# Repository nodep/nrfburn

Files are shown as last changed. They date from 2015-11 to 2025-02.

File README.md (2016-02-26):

# nrfburn
This is a hardware and software package for flashing Nordic Semiconductors nRF24LE1 and nRF24LU1+ microcontrollers. It consists of three parts: the flasher device with a USB connection, the firmware running on the flasher, and a host program which sends command to the flasher over the USB connection.

### The flasher

The flasher is based around an Atmel AVR ATmega88pa microcontroller running at 12MHz and 3.3V. The PCB is a mixture of through-hole and SMD components chosen as a compromise between size, ease of hand-soldering and mechanical robustness.

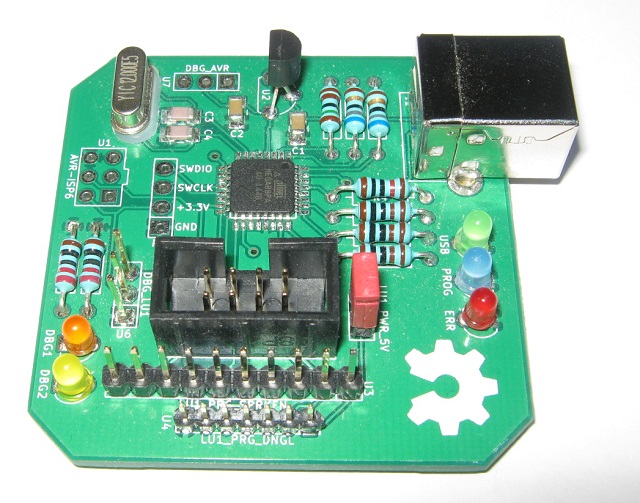
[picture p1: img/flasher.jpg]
the flasher v1.1


It has connectors with pin configurations which allow two popular nRF24LU1+ breakouts and dongles to be directly plugged into the flasher. One is the SparkFun Tranciever Breakout - nRF24LU1+, and the other is the popular nRF USB dongle from ebay.

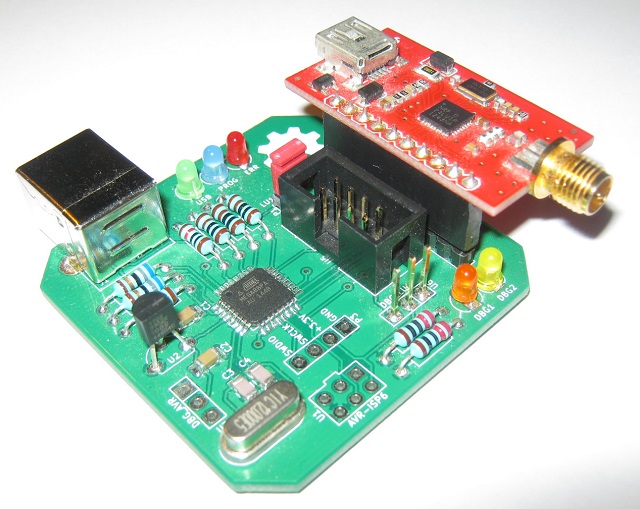
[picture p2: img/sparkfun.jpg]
the flasher and SparkFun

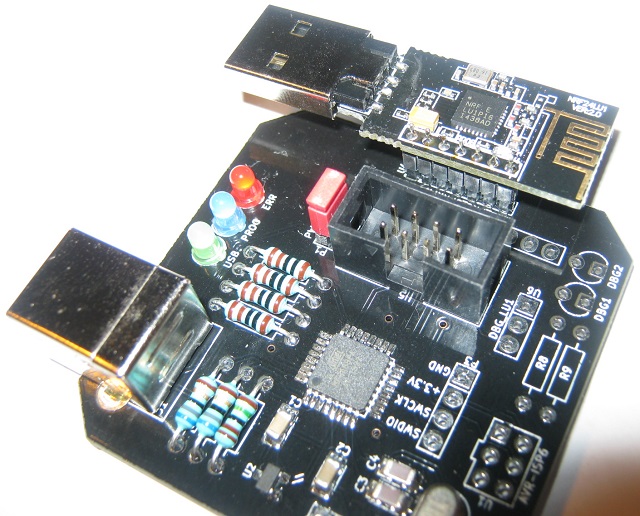
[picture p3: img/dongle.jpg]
the flasher and the ebay dongle


It also has an 8 pin flat cable connector through which it can flash nRF24LE1 devices as an in-system programmer.

The DBG_LU1 output can be used as a UART debug output from the nRF24LU1+ dongle. There are also two LEDs (DBG1 and DBG2) which can be driven from the SparkFun breakout. This is also useful for debugging.

### The firmware

The flasher firmware communicates with the host PC though [obdev's V-USB](https://www.obdev.at/products/vusb/index.html). It accepts commands from the PC, executes them and sends responses.

### The host PC

The program running on the host PC is a cross-platform (Windows and Linux) command line tool. It does not need special OS drivers because all communication is done through the USB HID class. It's been tested on Windows 7, 8 and 10 and on Linux running on Hardkernel's Odroid X2 board.

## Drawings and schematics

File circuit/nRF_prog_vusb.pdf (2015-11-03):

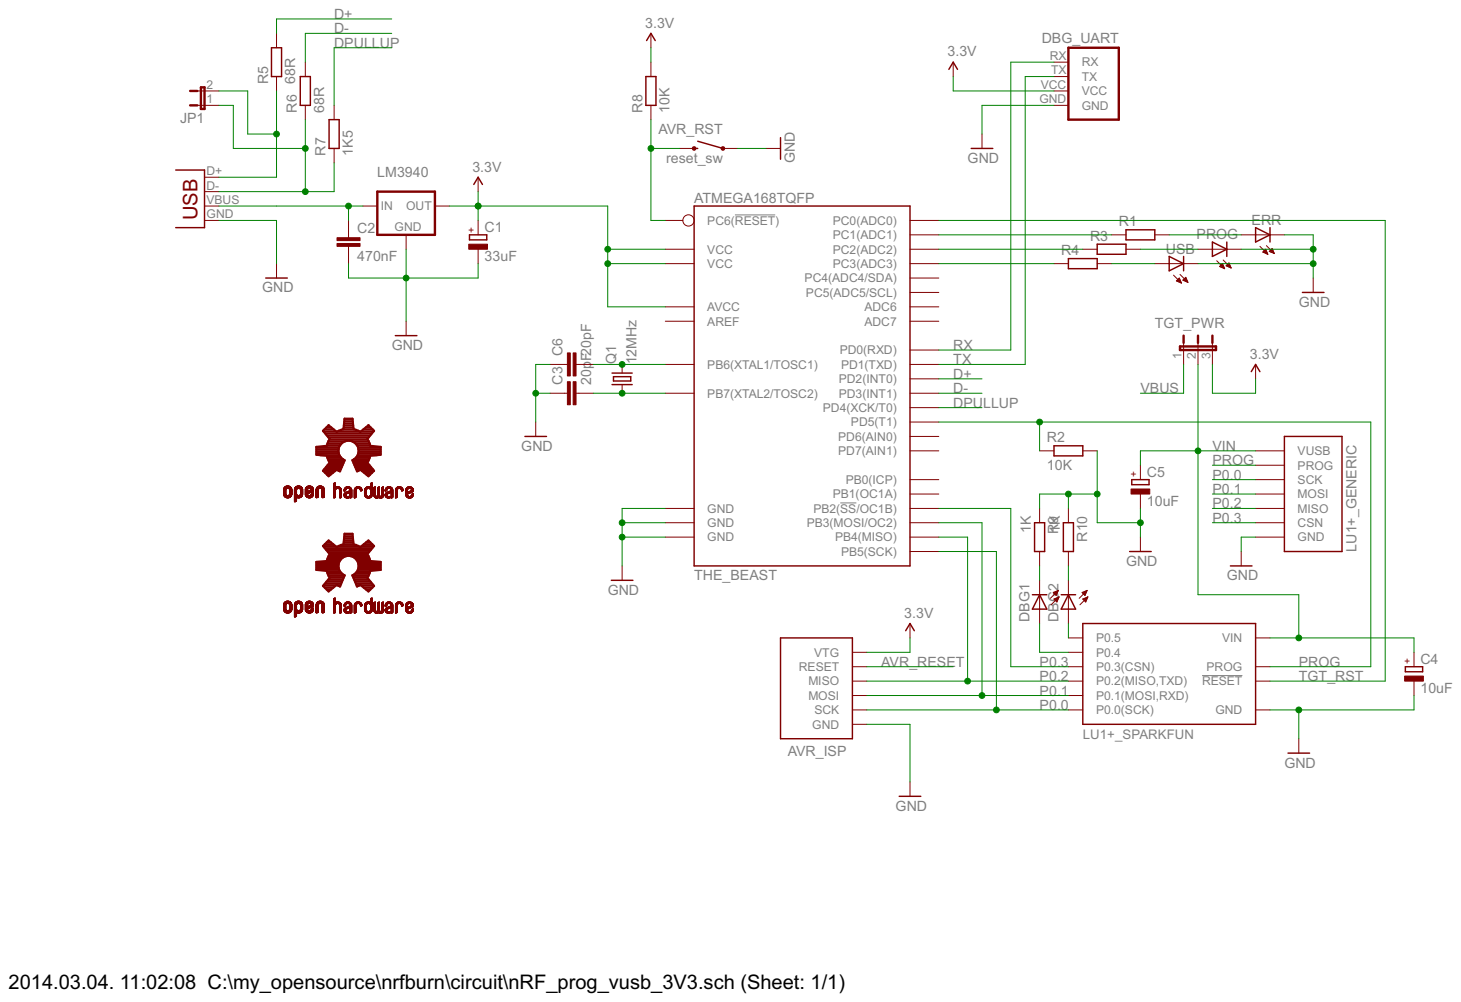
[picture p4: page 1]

2014.03.04. 11:02:08 C:\my_opensource\nrfburn\circuit\nRF_prog_vusb_3V3.sch (Sheet: 1/1)

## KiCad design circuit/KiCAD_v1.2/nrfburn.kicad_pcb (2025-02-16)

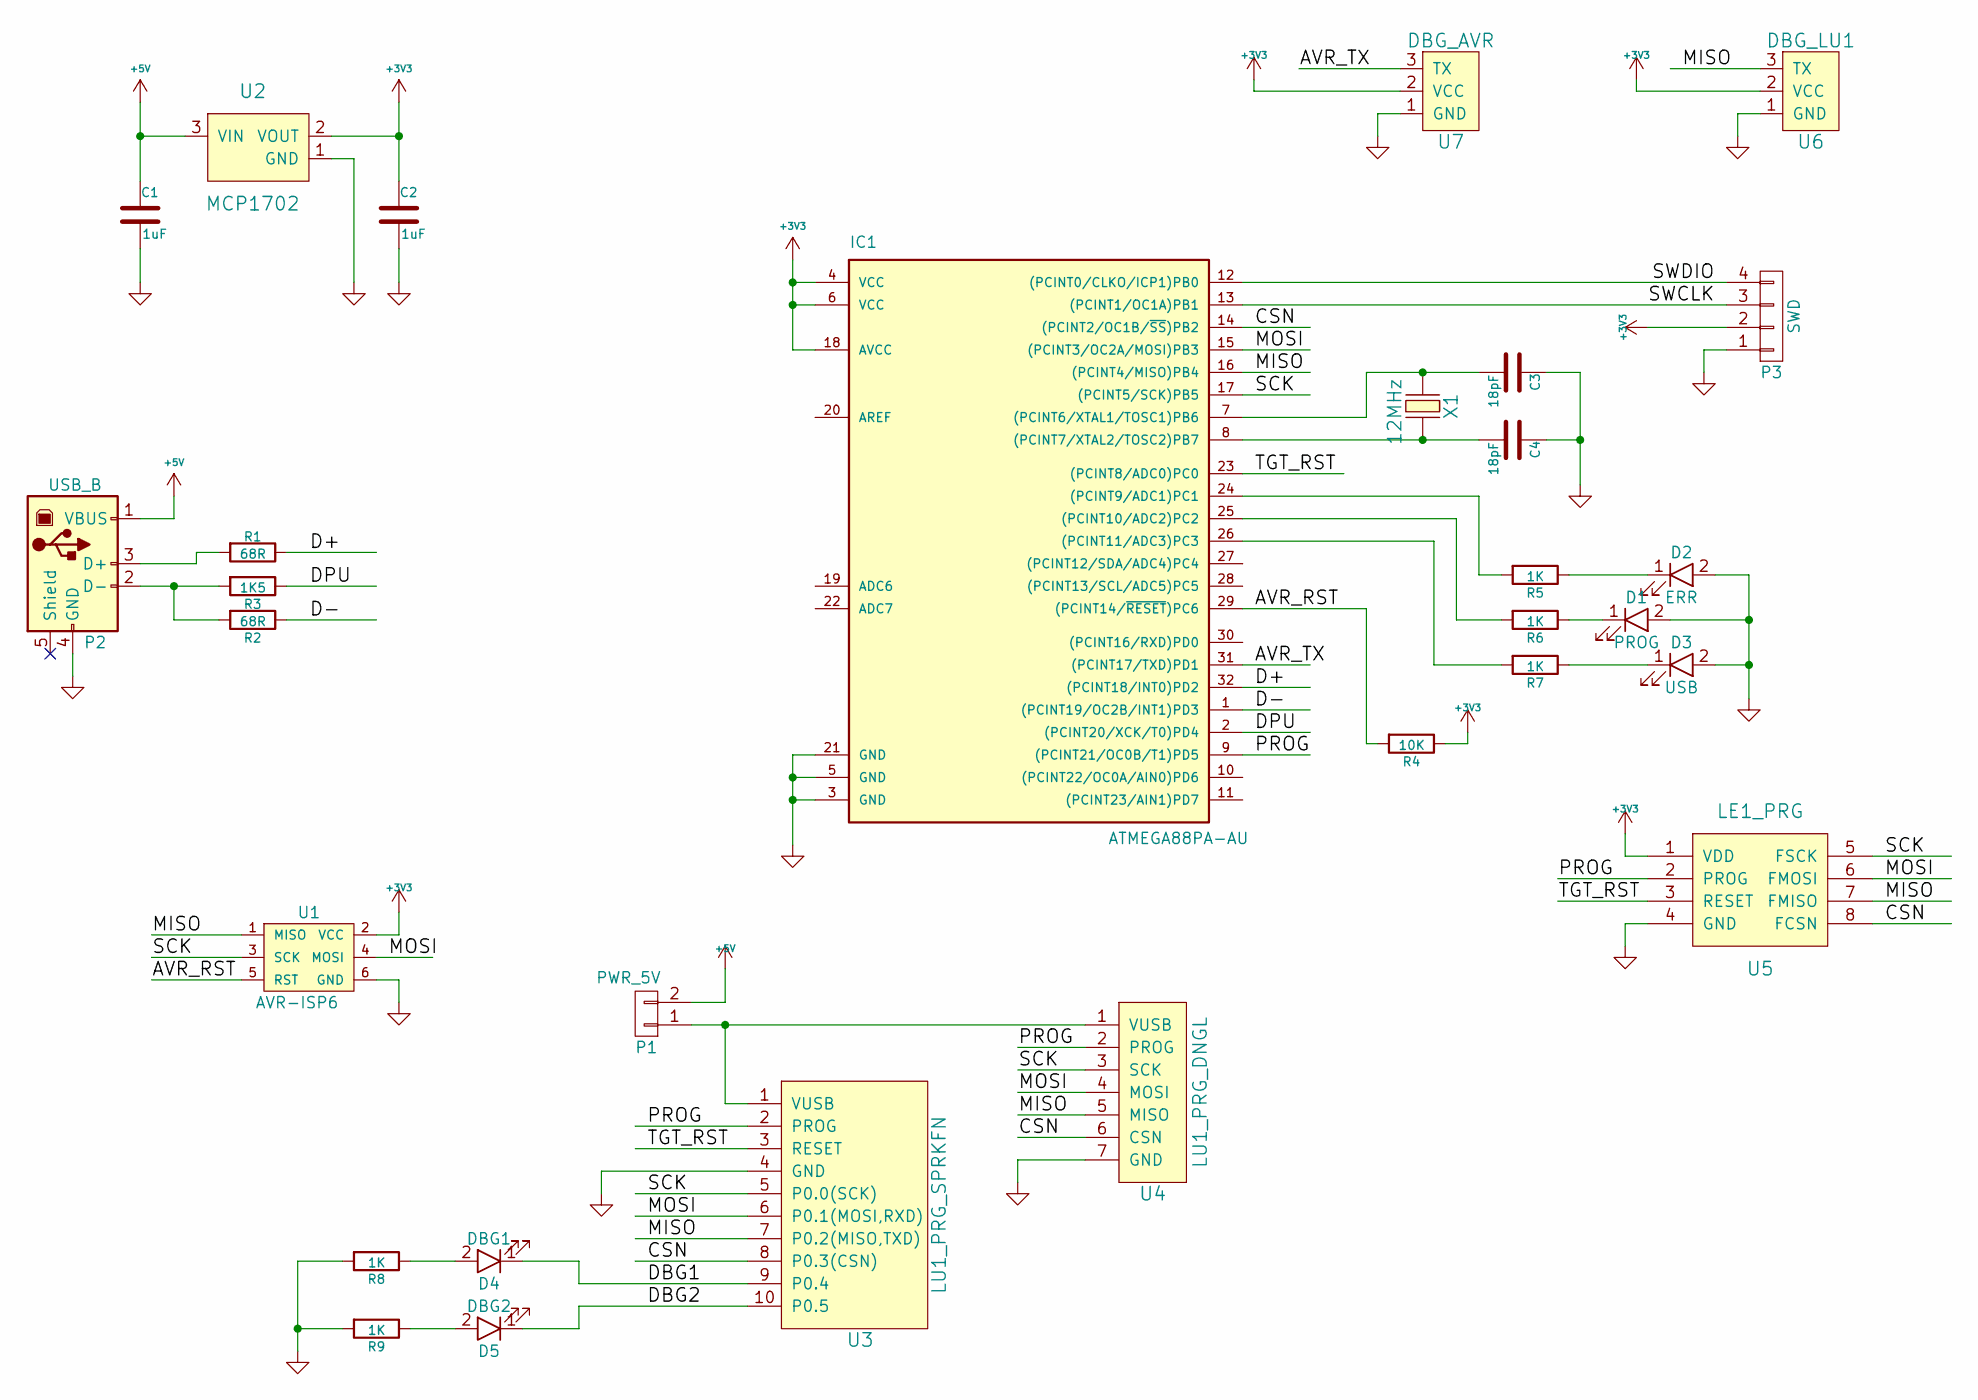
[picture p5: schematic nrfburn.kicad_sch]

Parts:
C1, C2: 1uF; c_1206
C3, C4: 18pF; c_1206
D1: PROG; LED-3MM
D2: ERR; LED-3MM
D3: USB; LED-3MM
D4: DBG1; LED-3MM
D5: DBG2; LED-3MM
IC1: ATMEGA88PA-AU; TQFP32
P1: PWR_5V; Pin_Header_Straight_1x02
P2: USB_B; USB_B_loc
P3: SWD; Pin_Header_Straight_1x04
R1, R2: 68R; Resistor_Horizontal_RM10mm
R3: 1K5; Resistor_Horizontal_RM10mm
R4: 10K; Resistor_Horizontal_RM10mm
R5, R6, R7, R8, R9: 1K; Resistor_Horizontal_RM10mm
U1: AVR-ISP6; AVR_ISP6
U2: MCP1702; SOT23
U3: LU1_PRG_SPRKFN; Pin_Header_Straight_1x10
U4: LU1_PRG_DNGL; LU1_PRG_DONGLE
U5: LE1_PRG; NRF_ICSP_RibbonCable
U6: DBG_LU1; Pin_Header_Straight_1x03
U7: DBG_AVR; Pin_Header_Straight_1x03
X1: 12MHz; Crystal_HC49-U_Vertical

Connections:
+3V3: C2.1, IC1.4 (VCC), IC1.6 (VCC), IC1.18 (AVCC), P3.2, R4.1, U1.2 (VCC), U2.2 (VOUT), U5.1 (VDD), U6.2 (VCC), U7.2 (VCC)
+5V: C1.1, P1.2, P2.1 (VBUS), U2.3 (VIN)
/AVR_RST: IC1.29 ((PCINT14/~RESET)PC6), R4.2, U1.5 (RST)
/AVR_TX: IC1.31 ((PCINT17/TXD)PD1), U7.3 (TX)
/CSN: IC1.14 ((PCINT2/OC1B/~SS)PB2), U3.8 (P0.3(CSN)), U4.6 (CSN), U5.8 (FCSN)
/D+: IC1.32 ((PCINT18/INT0)PD2), R1.1
/D-: IC1.1 ((PCINT19/OC2B/INT1)PD3), R2.1
/DBG1: D4.1 (K), U3.9 (P0.4)
/DBG2: D5.1 (K), U3.10 (P0.5)
/DPU: IC1.2 ((PCINT20/XCK/T0)PD4), R3.1
/MISO: IC1.16 ((PCINT4/MISO)PB4), U1.1 (MISO), U3.7 (P0.2(MISO,TXD)), U4.5 (MISO), U5.7 (FMISO), U6.3 (TX)
/MOSI: IC1.15 ((PCINT3/OC2A/MOSI)PB3), U1.4 (MOSI), U3.6 (P0.1(MOSI,RXD)), U4.4 (MOSI), U5.6 (FMOSI)
/PROG: IC1.9 ((PCINT21/OC0B/T1)PD5), U3.2 (PROG), U4.2 (PROG), U5.2 (PROG)
/SCK: IC1.17 ((PCINT5/SCK)PB5), U1.3 (SCK), U3.5 (P0.0(SCK)), U4.3 (SCK), U5.5 (FSCK)
/SWCLK: IC1.13 ((PCINT1/OC1A)PB1), P3.3
/SWDIO: IC1.12 ((PCINT0/CLKO/ICP1)PB0), P3.4
/TGT_RST: IC1.23 ((PCINT8/ADC0)PC0), U3.3 (RESET), U5.3 (RESET)
GND: C1.2, C2.2, C3.1, C4.1, D1.2 (A), D2.2 (A), D3.2 (A), IC1.3 (GND), IC1.5 (GND), IC1.21 (GND), P2.4 (GND), P3.1, R8.2, R9.2, U1.6 (GND), U2.1 (GND), U3.4 (GND), U4.7 (GND), U5.4 (GND), U6.1 (GND), U7.1 (GND)
unnamed: D1.1 (K), R6.1
unnamed: D2.1 (K), R5.1
unnamed: D3.1 (K), R7.1
unnamed: D4.2 (A), R8.1
unnamed: D5.2 (A), R9.1
unnamed: C3.2, IC1.7 ((PCINT6/XTAL1/TOSC1)PB6), X1.1
unnamed: C4.2, IC1.8 ((PCINT7/XTAL2/TOSC2)PB7), X1.2
unnamed: IC1.24 ((PCINT9/ADC1)PC1), R5.2
unnamed: IC1.25 ((PCINT10/ADC2)PC2), R6.2
unnamed: IC1.26 ((PCINT11/ADC3)PC3), R7.2
unnamed: P1.1, U3.1 (VUSB), U4.1 (VUSB)
unnamed: P2.3 (D+), R1.2
unnamed: P2.2 (D-), R2.2, R3.2

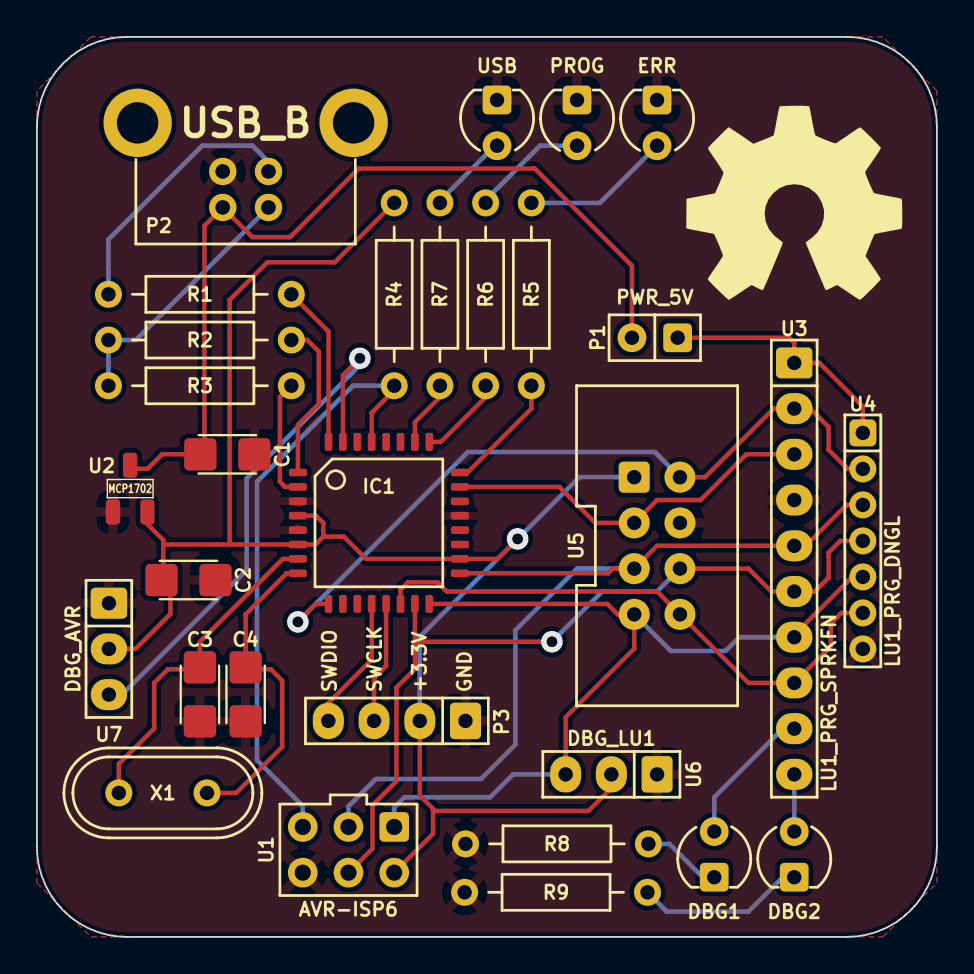
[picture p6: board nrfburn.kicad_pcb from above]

Board: 2 copper layers, 50.0 x 50.0 mm, 30 parts (0 on the bottom side), 31 nets.

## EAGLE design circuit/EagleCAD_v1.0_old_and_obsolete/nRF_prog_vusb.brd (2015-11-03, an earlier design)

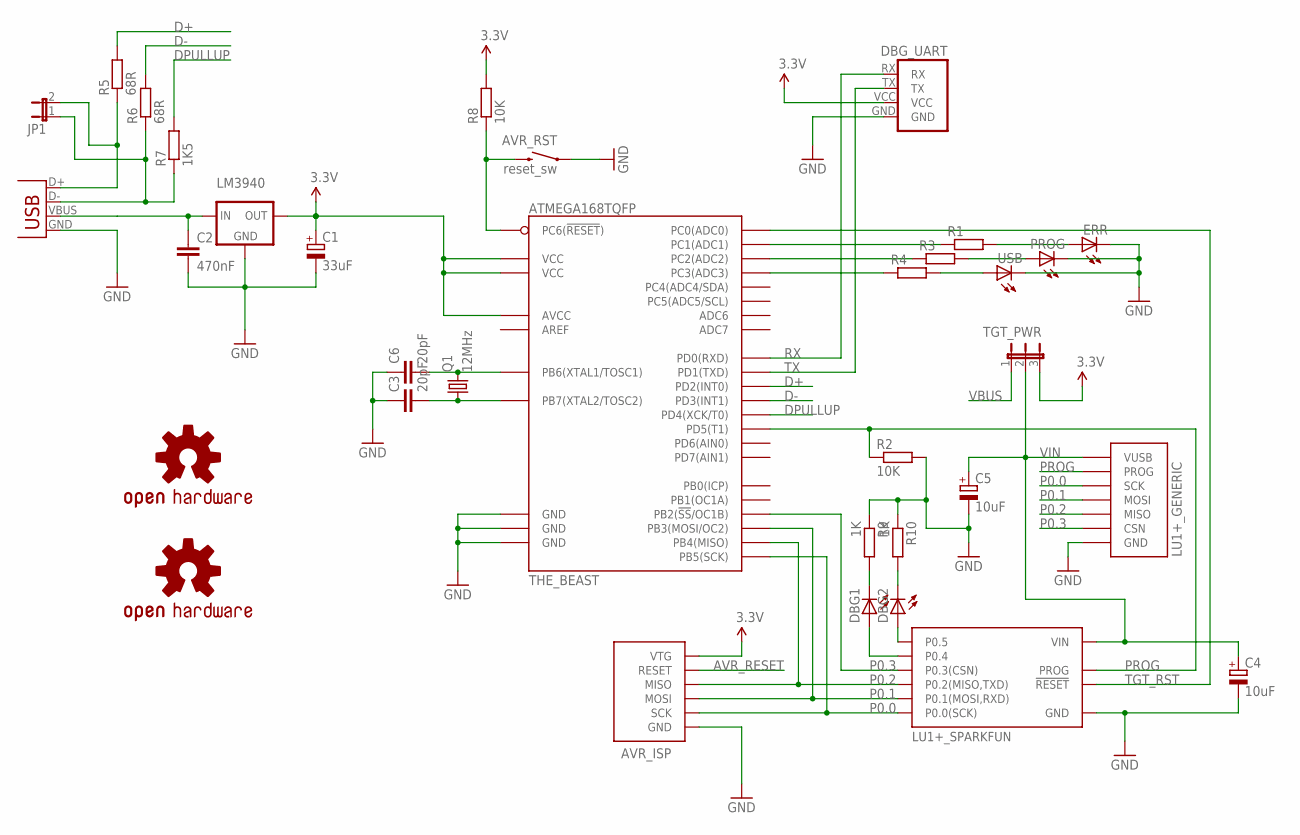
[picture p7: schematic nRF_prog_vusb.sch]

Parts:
AVR_ISP: AVR-ISP-6SMALL_FP; AVR-ISP-6-SMALL-FP
AVR_RST: reset_sw; TACTILE_SWITCH_SMD
C1: 33uF; SMC_B
C2: 470nF; C0805K
C3, C6: 20pF; C0805
C4, C5: 10uF; SMC_B
DBG1, DBG2: LEDCHIPLED_0805; CHIPLED_0805
DBG_UART: UART_PORT
ERR: LEDCHIPLED_0805; CHIPLED_0805
JP1: JP1E; JP1
LM3940: LM3940; SOT223
LU1+_GENERIC: NRF24LU1P_GENERIC
LU1+_SPARKFUN: NRF24LU1P_SPARKFUN_BREAKOUT; NRF24LU+_SPARKFUN_BREAKOUT
PROG: LEDCHIPLED_0805; CHIPLED_0805
Q1: 12MHz; QUARTZ
R1, R3, R4: R-EU_M0805; M0805
R2, R8: 10K; M0805
R5, R6: 68R; M0805
R7: 1K5; M0805
R9, R10: 1K; M0805
TGT_PWR: JP2E; JP2
THE_BEAST: ATMEGA168TQFP; TQFP32-08
U$1: OSHW-LOGOM; OSHW-LOGO-M
U$2: OSHW-LOGOL; OSHW-LOGO-L
USB: LEDCHIPLED_0805; CHIPLED_0805
USB-B: USBPTH; USB-B-PTH

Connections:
3.3V: AVR_ISP.VCC (VTG), C1.+, DBG_UART.VCC, LM3940.3 (OUT), R8.2, TGT_PWR.3, THE_BEAST.4 (VCC), THE_BEAST.6 (VCC), THE_BEAST.18 (AVCC)
AVR_RESET: AVR_ISP.RESET, AVR_RST.3 (2), R8.1, THE_BEAST.29 (PC6(!RESET!))
D+: R5.2, THE_BEAST.32 (PD2(INT0))
D-: R6.2, THE_BEAST.1 (PD3(INT1))
DPULLUP: R7.2, THE_BEAST.2 (PD4(XCK/T0))
GND: AVR_ISP.GND, AVR_RST.1, C1.-, C2.2, C3.1, C4.-, C5.-, C6.1, DBG_UART.GND, ERR.C, LM3940.2 (GND), LM3940.4 (GND), LU1+_GENERIC.GND, LU1+_SPARKFUN.GND, PROG.C, R2.2, R9.1, R10.1, THE_BEAST.3 (GND), THE_BEAST.5 (GND), THE_BEAST.21 (GND), USB.C, USB-B.GND
unnamed: DBG2.A, LU1+_SPARKFUN.P0.5
unnamed: DBG1.A, LU1+_SPARKFUN.P0.4
unnamed: DBG2.C, R10.2
unnamed: DBG1.C, R9.2
unnamed: R4.1, THE_BEAST.26 (PC3(ADC3))
unnamed: R3.1, THE_BEAST.25 (PC2(ADC2))
unnamed: R1.1, THE_BEAST.24 (PC1(ADC1))
unnamed: R4.2, USB.A
unnamed: PROG.A, R3.2
unnamed: ERR.A, R1.2
unnamed: C6.2, Q1.2, THE_BEAST.7 (PB6(XTAL1/TOSC1))
unnamed: C3.2, Q1.1, THE_BEAST.8 (PB7(XTAL2/TOSC2))
P0.0: AVR_ISP.SCK, LU1+_GENERIC.SCK, LU1+_SPARKFUN.P0.0 (P0.0(SCK)), THE_BEAST.17 (PB5(SCK))
P0.1: AVR_ISP.MOSI, LU1+_GENERIC.MOSI, LU1+_SPARKFUN.P0.1 (P0.1(MOSI,RXD)), THE_BEAST.15 (PB3(MOSI/OC2))
P0.2: AVR_ISP.MISO, LU1+_GENERIC.MISO, LU1+_SPARKFUN.P0.2 (P0.2(MISO,TXD)), THE_BEAST.16 (PB4(MISO))
P0.3: LU1+_GENERIC.CSN, LU1+_SPARKFUN.P0.3 (P0.3(CSN)), THE_BEAST.14 (PB2(!SS!/OC1B))
PROG: LU1+_GENERIC.PROG, LU1+_SPARKFUN.PROG, R2.1, THE_BEAST.9 (PD5(T1))
RX: DBG_UART.RX, THE_BEAST.30 (PD0(RXD))
TGT_RST: LU1+_SPARKFUN.RESET (!RESET!), THE_BEAST.23 (PC0(ADC0))
TX: DBG_UART.TX, THE_BEAST.31 (PD1(TXD))
USB_D+: JP1.2, R5.1, USB-B.D+
USB_D-: JP1.1, R6.1, R7.1, USB-B.D-
VBUS: C2.1, LM3940.1 (IN), TGT_PWR.1, USB-B.VBUS
VIN: C4.+, C5.+, LU1+_GENERIC.VUSB, LU1+_SPARKFUN.VIN, TGT_PWR.2

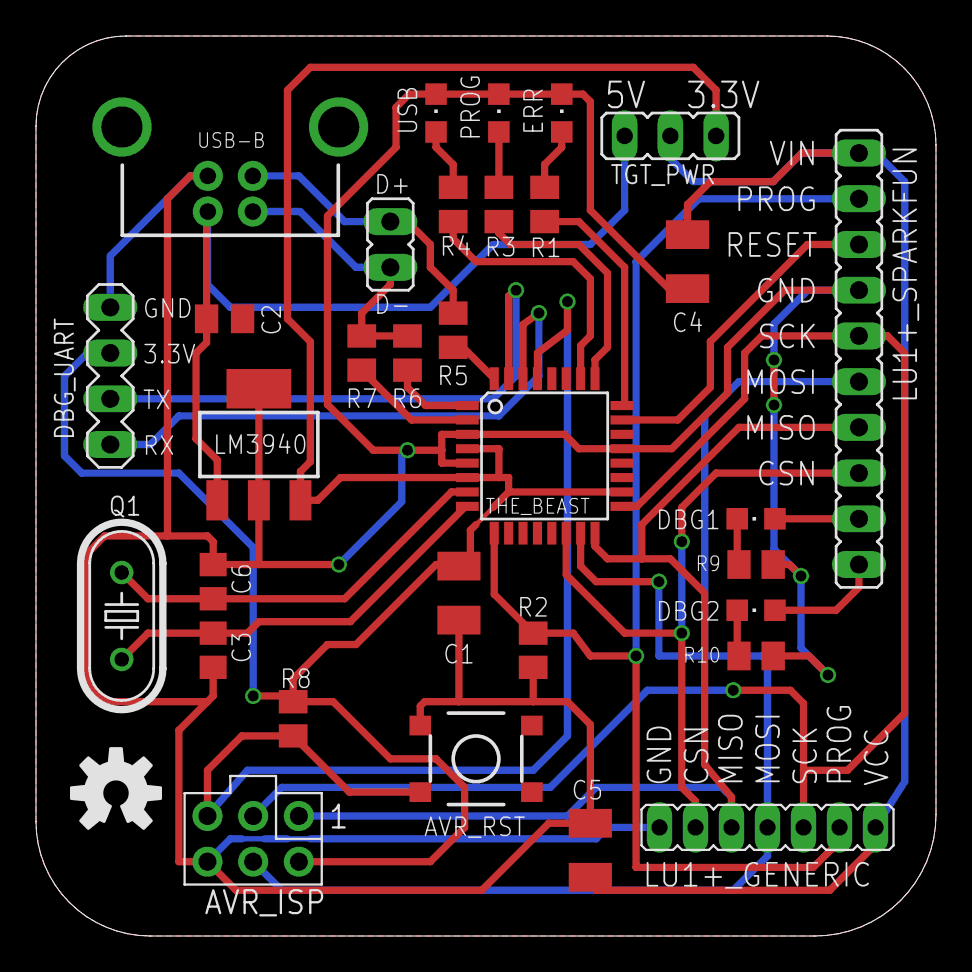
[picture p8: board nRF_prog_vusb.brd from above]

Board: 2 copper layers, 50.0 x 50.0 mm, 34 parts (1 on the bottom side), 30 nets.

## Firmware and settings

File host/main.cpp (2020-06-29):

#include <stdio.h>
#include <string.h>
#include <stdint.h>
#include <stdlib.h>
#include <time.h>

#include <string>
#include <vector>

#include "programmer.h"
#include "flashmem.h"
#include "utils.h"
#include "bootloader.h"

void PrintVer()
{
	puts("nrfburn v0.1  build " __DATE__ " " __TIME__);
}

void PrintHelp()
{
	PrintVer();
	puts("Usage: nrfburn [options]");
	puts("Options:");
	puts("  -f 16|32       Specify flash size in kilobytes. Only 16 or 32 are valid.");
	puts("  -w <filename>  Write contents of HEX file to nRF target MainBlock flash.");
	puts("                 Automatically performs a chip erase before programming.");
	puts("                 Runs a verification pass after writing is complete.");
	puts("  -v <filename>  Verify nRF target MainBlock with contents of HEX file.");
	puts("  -r <filename>  Read nRF target MainBlock into HEX file.");
	puts("  -p <filename>  Read nRF target InfoPage into HEX file.");
	puts("  -e             Perform a chip erase. This erases only the MainBlock, ");
	puts("                 and leaves the InfoPage intact.");
	puts("  -i <chipID>    Erase the InfoPage and write the specified chip ID.");
	puts("                 This also performs a chip erase. chipID must be in the");
	puts("                 the format xx-xx-xx-xx-xx where x is a hex digit.");
	puts("                 WARNING!");
	puts("                 Don't do this unless you know exactly what you're doing!");
	puts("                 Erasing the InfoPage on a nRF24LE1 will erase the chip's");
	puts("                 calibration information which you do not want.");
	puts("  -d mb|ip       Disable SPI reading of MainBlock or InfoPage.");
	puts("  -s             Reset the target nRF chip.");
	puts("  -b <filename>  Update programmer firmware from HEX.");
	puts("");
}

struct Options
{
	std::string		WriteMBFrom;	// HEX -> MainBlock
	std::string		ReadMBInto;		// MainBlock -> HEX
	std::string		VerifyMBWith;	// HEX with MainBlock
	std::string		ReadIPInto;		// InfoPage -> HEX
	uint8_t			ChipID[CHIP_ID_BYTES];
	uint8_t			ChipID_len;
	int				DisableReadback;
	int				FlashSize;
	bool			EraseAll;
	bool			ResetTarget;
	std::string		HexForBootloader;	// HEX to send to programmer bootloader

	Options()
		: ChipID_len(0), DisableReadback(DISABLE_NONE), FlashSize(0), EraseAll(false), ResetTarget(false)
	{}

	void ParseArgs(const int argc, const char* argv[]);
};

void Options::ParseArgs(const int argc, const char* argv[])
{
	int c = 1;
	while (c < argc)
	{
		if (argv[c] == NULL  ||  *argv[c] != '-'  ||  strlen(argv[c]) < 2)
			throw std::string("Invalid argument.");

		switch (argv[c][1])
		{
		case 'w':
			++c;

			if (c < argc)
				WriteMBFrom = argv[c];
			else
				throw std::string("Invalid HEX file name.");

			break;
		case 'r':
			++c;

			if (c < argc)
				ReadMBInto = argv[c];
			else
				throw std::string("Invalid HEX file name.");

			break;
		case 'p':
			++c;

			if (c < argc)
				ReadIPInto = argv[c];
			else
				throw std::string("Invalid HEX file name.");

			break;
		case 'e':
			EraseAll = true;
			break;
		case 'f':
			++c;

			FlashSize = 0;
			
			if (c < argc)
			{
				if (strcmp(argv[c], "16") == 0)
					FlashSize = 16*1024;
				else if (strcmp(argv[c], "32") == 0)
					FlashSize = 32*1024;
			}
			
			if (FlashSize == 0)
				throw std::string("Invalid flash size. Only 16 or 32 are valid.");
			
			break;
		case 'i':
			++c;

			if (c < argc)
			{
				const char* pEnd = argv[c];
				ChipID_len = 0;
				while (*pEnd)
				{
					long int res = strtol(pEnd, (char**) &pEnd, 16);
					if (res < 0  ||  res > 0xff  ||  (*pEnd != '\0'  &&  *pEnd != '-'))
						throw std::string("Incorrect ChipID format.");

					ChipID[ChipID_len++] = uint8_t(res);
					
					if (*pEnd)	// skip the dash
						pEnd++;
				}
				
				if (ChipID_len != CHIP_ID_BYTES)
					throw std::string("Incorrect ChipID length.");
				
			} else {
				throw std::string("ChipID not specified.");
			}

			break;
		case 'v':
			++c;

			if (c < argc)
				VerifyMBWith = argv[c];
			else
				throw std::string("Invalid HEX file name.");
				
			break;
			
		case 'd':
			++c;
			
			DisableReadback = DISABLE_NONE;
			
			if (c < argc)
			{
				if (strcasecmp(argv[c], "mb") == 0)
					DisableReadback = DISABLE_MB;
				else if (strcasecmp(argv[c], "ip") == 0)
					DisableReadback = DISABLE_IP;
			}

			if (DisableReadback == DISABLE_NONE)
				throw std::string("Invalid -d argument. Only mb or ip are allowed.");
			
			break;
			
		case 's':
			ResetTarget = true;
			break;
			
		case 'b':
			++c;

			if (c < argc)
				HexForBootloader = argv[c];
			else
				throw std::string("Invalid HEX file name.");

			break;
			
		default:
			throw std::string("Invalid command line option: -") + argv[c][1];
			break;
		}

		++c;
	}
	
	//
	// validate the args
	//

	if ((!WriteMBFrom.empty()  ||  !ReadMBInto.empty() ||  !VerifyMBWith.empty())  &&  FlashSize == 0)
		throw std::string("Flash size not specified");
	
	int cnt = 0;
	
	cnt += WriteMBFrom.empty() ? 0 : 1;
	cnt += ReadMBInto.empty() ? 0 : 1;
	cnt += VerifyMBWith.empty() ? 0 : 1;
	cnt += ReadIPInto.empty() ? 0 : 1;
	cnt += ChipID_len ? 1 : 0;
	cnt += EraseAll ? 1 : 0;
	cnt += ResetTarget ? 1 : 0;
	cnt += DisableReadback != DISABLE_NONE ? 1 : 0;
	cnt += HexForBootloader.empty() ? 0 : 1;
	
	if (cnt > 1)
		throw std::string("Mutually exclusive options selected.");
}

std::string int2str(const int i)
{
	char buff[32];
	snprintf(buff, sizeof buff, "%d", i);
	return buff;
}

std::string int2hex(const unsigned short i)
{
	char buff[32];
	snprintf(buff, sizeof buff, "0x%04x", i);
	return buff;
}

void DoProg(const Options& opt)
{
	// open the programmer
	Programmer prg(opt.FlashSize);

	printf("\nOpening programmer\n");
	prg.Open();
	
	// just reset the target and return
	if (opt.ResetTarget)
	{
		puts("");
		prg.ResetTarget();
		puts("\nTarget has been reset.");
		return;
	}	
	
	puts("Reading Flash registers");
	prg.BeginProgramming();
	
	// print the FSR and FPCR
	printf("\nnRF device flash registers:\n");
	printf("FPCR = 0x%02x\n", prg.GetFPCR());
	printf("FSR  = 0x%02x    DBG=%i  STP=%i  RDISMB=%i  RDISIP=%i\n",
					prg.GetFSR(),
					prg.GetFSR() & (1<<FSR_DBG) ? 1 : 0,
					prg.GetFSR() & (1<<FSR_STP) ? 1 : 0,
					prg.GetFSR() & (1<<FSR_RDISMB) ? 1 : 0,
					prg.GetFSR() & (1<<FSR_RDISIP) ? 1 : 0);

	printf("\nMainBlock readback %s\nInfoPage readback %s\n\n",
					prg.CanReadMainBlock() ? "enabled" : "disabled",
					prg.CanReadInfoPage() ? "enabled" : "disabled");

	// check if the target nRF device is present.
	// if the nRF is not present, we will read the FSR register as 0xff.
	// 0xff is not a valid value on a powered nRF, because bit 0 is always
	// read as 0.
	if (!prg.IsTargetPresent())
		throw std::string("FSR == 0xff. Target device not found.");
	
	if (opt.EraseAll)
	{
		prg.EraseAll();
	} else if (!opt.WriteMBFrom.empty()) {
		prg.WriteMainBlock(opt.WriteMBFrom);
		prg.VerifyMainBlock(opt.WriteMBFrom, true);
		printf("\nMainBlock flash written from %s\n", opt.WriteMBFrom.c_str());
	} else if (!opt.ReadMBInto.empty()) {
		prg.ReadMainBlock(opt.ReadMBInto);
		printf("\nMainBlock contents saved into %s\n", opt.ReadMBInto.c_str());
	} else if (!opt.VerifyMBWith.empty()) {
		prg.VerifyMainBlock(opt.VerifyMBWith);
		printf("\nMainBlock flash verified with %s\n", opt.VerifyMBWith.c_str());
	} else if (!opt.ReadIPInto.empty()) {
		prg.ReadInfoPage(opt.ReadIPInto);
		printf("\nInfoPage contents saved into %s\n", opt.ReadIPInto.c_str());
	} else if (opt.DisableReadback != DISABLE_NONE) {
		prg.DisableReadback(opt.DisableReadback);
		printf("\nSPI readback of %s disabled.\n", opt.DisableReadback == DISABLE_MB ? "MainBlock" : "InfoPage");
	} else if (opt.ChipID_len) {
		prg.WriteInfoPage(opt.ChipID);
		printf("\nChipID %02x-%02x-%02x-%02x-%02x written.\n",	opt.ChipID[0],
																opt.ChipID[1],
																opt.ChipID[2],
																opt.ChipID[3],
																opt.ChipID[4]);
	}
}

int main(const int argc, const char* argv[])
{
	try {
		Options opt;
		if (argc == 1)
		{
			PrintHelp();
			return 1;
		}

		PrintVer();
		
		opt.ParseArgs(argc, argv);

		if (!opt.HexForBootloader.empty())
			DoBootload(opt.HexForBootloader);
		else
			DoProg(opt);

	} catch (std::string& e) {
		fprintf(stderr, "\nError: %s\n", e.c_str());
		return 1;
	}

	return 0;
}

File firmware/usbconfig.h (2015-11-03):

/* Name: usbconfig.h
 * Project: V-USB, virtual USB port for Atmel's(r) AVR(r) microcontrollers
 * Author: Christian Starkjohann
 * Creation Date: 2005-04-01
 * Tabsize: 4
 * Copyright: (c) 2005 by OBJECTIVE DEVELOPMENT Software GmbH
 * License: GNU GPL v2 (see License.txt), GNU GPL v3 or proprietary (CommercialLicense.txt)
 */

#ifndef __usbconfig_h_included__
#define __usbconfig_h_included__

/*
General Description:
This file is an example configuration (with inline documentation) for the USB
driver. It configures V-USB for USB D+ connected to Port D bit 2 (which is
also hardware interrupt 0 on many devices) and USB D- to Port D bit 4. You may
wire the lines to any other port, as long as D+ is also wired to INT0 (or any
other hardware interrupt, as long as it is the highest level interrupt, see
section at the end of this file).
*/

/* ---------------------------- Hardware Config ---------------------------- */

#define USB_CFG_IOPORTNAME      D
/* This is the port where the USB bus is connected. When you configure it to
 * "B", the registers PORTB, PINB and DDRB will be used.
 */
#define USB_CFG_DMINUS_BIT      3
/* This is the bit number in USB_CFG_IOPORT where the USB D- line is connected.
 * This may be any bit in the port.
 */
#define USB_CFG_DPLUS_BIT       2
/* This is the bit number in USB_CFG_IOPORT where the USB D+ line is connected.
 * This may be any bit in the port. Please note that D+ must also be connected
 * to interrupt pin INT0! [You can also use other interrupts, see section
 * "Optional MCU Description" below, or you can connect D- to the interrupt, as
 * it is required if you use the USB_COUNT_SOF feature. If you use D- for the
 * interrupt, the USB interrupt will also be triggered at Start-Of-Frame
 * markers every millisecond.]
 */
#define USB_CFG_CLOCK_KHZ       (F_CPU/1000)
/* Clock rate of the AVR in kHz. Legal values are 12000, 12800, 15000, 16000,
 * 16500, 18000 and 20000. The 12.8 MHz and 16.5 MHz versions of the code
 * require no crystal, they tolerate +/- 1% deviation from the nominal
 * frequency. All other rates require a precision of 2000 ppm and thus a
 * crystal!
 * Since F_CPU should be defined to your actual clock rate anyway, you should
 * not need to modify this setting.
 */
#define USB_CFG_CHECK_CRC       0
/* Define this to 1 if you want that the driver checks integrity of incoming
 * data packets (CRC checks). CRC checks cost quite a bit of code size and are
 * currently only available for 18 MHz crystal clock. You must choose
 * USB_CFG_CLOCK_KHZ = 18000 if you enable this option.
 */

/* ----------------------- Optional Hardware Config ------------------------ */

#define USB_CFG_PULLUP_IOPORTNAME   D
/* If you connect the 1.5k pullup resistor from D- to a port pin instead of
 * V+, you can connect and disconnect the device from firmware by calling
 * the macros usbDeviceConnect() and usbDeviceDisconnect() (see usbdrv.h).
 * This constant defines the port on which the pullup resistor is connected.
 */
#define USB_CFG_PULLUP_BIT          4
/* This constant defines the bit number in USB_CFG_PULLUP_IOPORT (defined
 * above) where the 1.5k pullup resistor is connected. See description
 * above for details.
 */

/* --------------------------- Functional Range ---------------------------- */
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

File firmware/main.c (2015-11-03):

#include <stdint.h>
#include <stdbool.h>
#include <stdio.h>

#include <avr/io.h>
#include <avr/interrupt.h>
#include <util/delay.h>

#include "hw_setup.h"
#include "avrdbg.h"
#include "avrutils.h"
#include "prg_spi.h"
#include "prg_parse.h"
#include "usbdrv.h"

void init_hw(void)
{
	// the LEDs
	SetBit(DDR(LED_ERR_PORT), LED_ERR_BIT);
	ClrBit(PORT(LED_ERR_PORT), LED_ERR_BIT);

	SetBit(DDR(LED_PROG_PORT), LED_PROG_BIT);
	ClrBit(PORT(LED_PROG_PORT), LED_PROG_BIT);

	SetBit(DDR(LED_USB_PORT), LED_USB_BIT);
	ClrBit(PORT(LED_USB_PORT), LED_USB_BIT);

#ifndef	ON_USBASP
	dbgInit();			// init the UART debug output (only possible on the nrfBurn board)
#endif
	
	progParseInit();	// init the programming protocol interface

	ProgSpiInit();		// init the programming hardware (SPI and the rest of the pins)
	
	// setup v-usb
	usbInit();
	usbDeviceDisconnect();	// enforce re-enumeration, do this while interrupts are disabled!
	_delay_ms(260);
	usbDeviceConnect();

	// enable interrupts
	sei();
}

/*
void swdLineReset(void)
{
	// drive 1
	SetBit(PORT(SWDIO_PORT), SWDIO_BIT);

	int i;
	for (i = 0; i < 100; i++)
	{
		TogBit(PORT(SWDCLK_PORT), SWDCLK_BIT);
		TogBit(PORT(SWDIO_PORT), SWDIO_BIT);
	}
}

typedef union swd_packet_t
{
	uint8_t		val;
	struct {
		unsigned int	start : 1;		// always 1
		unsigned int	is_ap : 1;		// 1 == APACC, 0 == DPACC
		unsigned int	is_read : 1;	// 1 == read, 0 = write
		unsigned int	reg_addr2 : 1;	// bits 2 & 3 of DP or AP register address
		unsigned int	reg_addr3 : 1;	//
		unsigned int	parity : 1;		//
		unsigned int	stop : 1;		//
		unsigned int	park : 1;		//
	} bits;
} swd_packet_t;

const uint8_t parity_calc[] = 
{
	0b100,		// 0b10000
	0b000,		// 0b10001
	0b000,		// 0b10010
	0b100,		// 0b10011
	0b000,		// 0b10100
	0b100,		// 0b10101
	0b100,		// 0b10110
	0b000,		// 0b10111
	0b000,		// 0b11000
	0b100,		// 0b11001
	0b100,		// 0b11010
	0b000,		// 0b11011
	0b100,		// 0b11100
	0b000,		// 0b11101
	0b000,		// 0b11110
	0b100,		// 0b11111
};

#define _NOP() do { __asm__ __volatile__ ("nop"); } while (0) 

void swdSendPacket(swd_packet_t pckt)
{
	SWDIO_OUT();
	
	uint8_t out_val = (pckt.val & 0b11111011) | 0b10000010;

	out_val |= parity_calc[(out_val >> 3) & 0x0f];
	
	SWDCLK_LO();
	
	out_val & 0x80 ? SWDIO_HI() : SWDIO_LO();
	
	SWDCLK_HI();
	_NOP();_NOP();_NOP();_NOP();_NOP();
	SWDCLK_LO();

	out_val & 0x40 ? SWDIO_HI() : SWDIO_LO();
	
	SWDCLK_HI();
	_NOP();_NOP();_NOP();_NOP();_NOP();
	SWDCLK_LO();
	
	out_val & 0x20 ? SWDIO_HI() : SWDIO_LO();

	SWDCLK_HI();
	_NOP();_NOP();_NOP();_NOP();_NOP();
	SWDCLK_LO();
	
	out_val & 0x10 ? SWDIO_HI() : SWDIO_LO();

	SWDCLK_HI();
	_NOP();_NOP();_NOP();_NOP();_NOP();
	SWDCLK_LO();

	out_val & 0x08 ? SWDIO_HI() : SWDIO_LO();
	
	SWDCLK_HI();
	_NOP();_NOP();_NOP();_NOP();_NOP();
	SWDCLK_LO();
	
	out_val & 0x04 ? SWDIO_HI() : SWDIO_LO();

	SWDCLK_HI();
	_NOP();_NOP();_NOP();_NOP();_NOP();
	SWDCLK_LO();
	
	out_val & 0x02 ? SWDIO_HI() : SWDIO_LO();
	_NOP();_NOP();

	SWDCLK_HI();
	_NOP();_NOP();_NOP();_NOP();_NOP();
	SWDCLK_LO();

	SWDIO_PU_ON();	
	SWDIO_IN();		// park
	_NOP();_NOP();_NOP();
	
	SWDCLK_HI();
}

struct swd_operation_t
{
	swd_packet_t	packet;
	uint8_t			ack;
	uint32_t		data;
};

int main(void)
{
	SetBit(DDR(SWDCLK_PORT), SWDCLK_BIT);
	SetBit(DDR(SWDIO_PORT), SWDIO_BIT);

	while (1)
	{
		swdLineReset();
		_delay_ms(1);
		
		swd_packet_t pckt;
		pckt.bits.is_ap = 1;
		pckt.bits.is_read = 0;
		pckt.bits.reg_addr2 = 1;
		pckt.bits.reg_addr3 = 0;
		swdSendPacket(pckt);

		_delay_ms(10);
	}

	return 0;
}
*/

int main(void)
{
	init_hw();
	
	for (;;)
	{
		// poll the V-USB library
		usbPoll();

		// turn the USB LED on if we are configured
		if (usbConfiguration != 0)
			SetBit(PORT(LED_USB_PORT), LED_USB_BIT);
		else
			ClrBit(PORT(LED_USB_PORT), LED_USB_BIT);
		
		// handle the requests, and create responses
		progParsePoll();
	}
}

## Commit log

2015-11-03 initial circuit commit
    [nRF_prog_vusb.brd, nRF_prog_vusb.sch, nrfburn.kicad_pcb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]
2016-02-26 File and folder name cleanup
    [nRF_prog_vusb.brd, nRF_prog_vusb.sch, nrfburn.kicad_pcb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]
2016-02-26 KiCad schematic and PCB for usable with the new KiCad release (4.0.1)
    [nrfburn.kicad_pcb, nrfburn.sch]
2020-06-29 replaced auto_ptr<> with vector<>
    [main.cpp]
2025-02-16 moved HW design to KiCad 8
    [nrfburn.kicad_pcb, nrfburn.kicad_sch, nrfburn.sch]
2025-02-16 added 3D models
    [nrfburn.kicad_pcb, nrfburn.kicad_sch]

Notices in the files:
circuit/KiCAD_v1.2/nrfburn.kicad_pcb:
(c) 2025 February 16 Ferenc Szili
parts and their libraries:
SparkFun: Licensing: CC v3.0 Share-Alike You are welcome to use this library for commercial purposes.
